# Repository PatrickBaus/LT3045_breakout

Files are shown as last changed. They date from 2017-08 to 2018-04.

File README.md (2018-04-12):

LT3042/LT3045 Breakout Board
===================

This repository contains the KiCAD PCB project files for a breakout board for the Linear Technologies LT3042/LT3045  ultralow noise, ultrahigh PSRR, 200/500 mA LDO regulator (http://www.linear.com/product/LT3042, http://www.linear.com/product/LT3045).

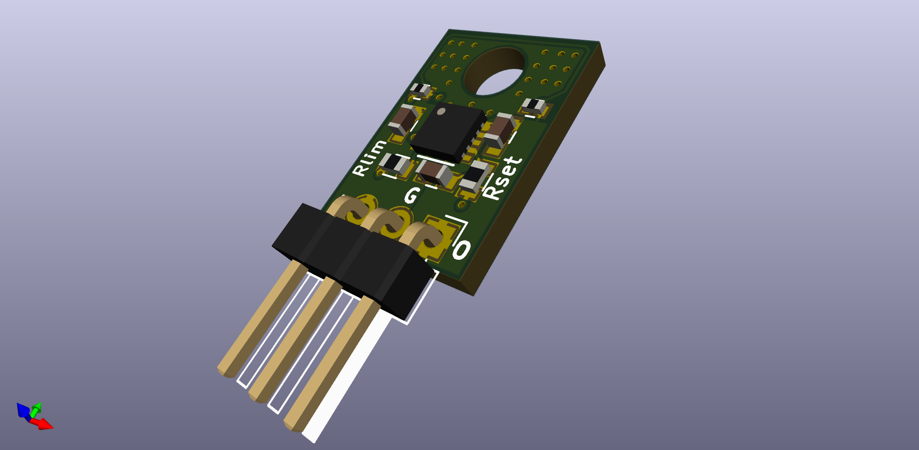
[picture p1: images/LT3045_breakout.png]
LT3045 breakout board


About
-----
This breakout board supports both the LT3042 and LT3045 LDO regulator. The package is designed as a drop-in replacement for the popular 78xx series.

The root folder contains the KiCAD files and the bill of materials, while the gerber files can be found in the [/gerber](gerber/) folder.

Thermal considerations
-----
The breakout board was tested with an LT3045 with different heat sink configurations to give an estimate on the expected temperature rise. This should help with the decision whether to add a heat sink or not. The test was done using a 35 µm (1 oz./ft²) copper board. The LT3045 was configured for an 11 V output from a 13 V input running at ~500 mA.

Using a thermal imaging camera the temperature was measured and the thermal resistance was calculated using the known ambient temperature (~23 °C).

##### No Heat Sink
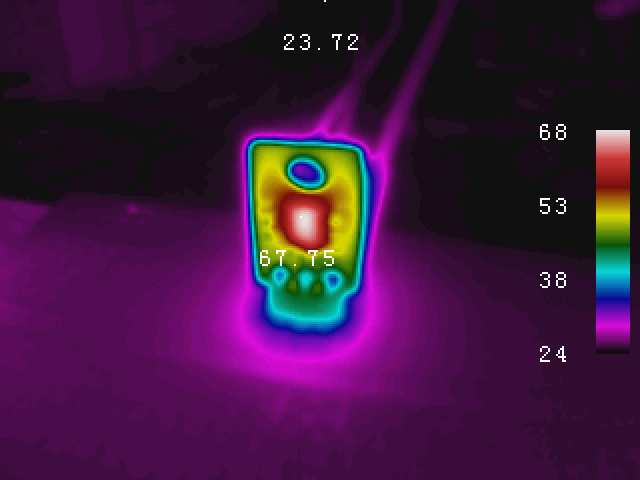
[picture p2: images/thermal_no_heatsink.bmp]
LT3045 no heat sink


##### Using a 25 K/W Heat Sink
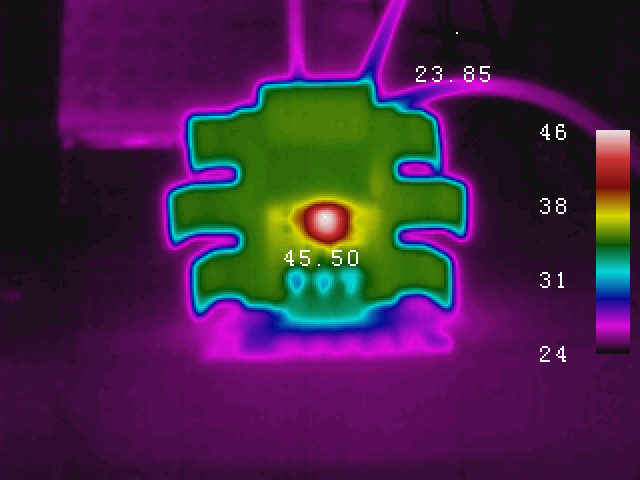
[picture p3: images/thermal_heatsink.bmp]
LT3045 + heat sink

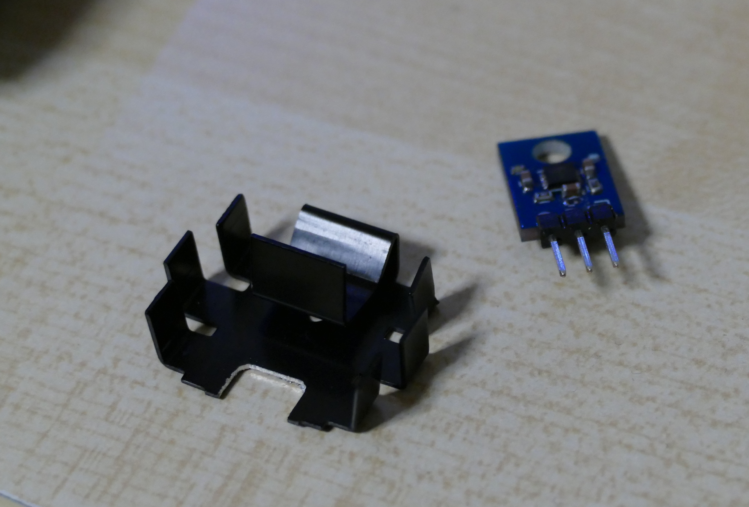
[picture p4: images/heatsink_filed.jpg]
Heat sink filed out


Dropping 2 V @ 500 mA, a Fischer Elekronik [FK 220 SA 220](http://www.fischerelektronik.de/web_fischer/en_GB/heatsinks/C02/Attachable%20heatsink/PR/FK220_SA_220_/datasheet.xhtml) heat sink was used without any thermal compound. Because of the mounting style of the pin header (contacts on the back side of the board) some slight modification of the heat sink is required. A small cutout needs to be made using a file. If the heatsink is to be attached permanetely some thermal adhesive to glue it in place is recommended.

##### Summary Table

|Heat Sink|Power Dissipated|Thermal Resistance|
|---|---|---|
|None |~1 W |~44 K/W |
|25 K/W |~1 W |~22 K/W |

I do recommend using a heat sink or bolting the LT3045 PCB down onto the main PCB when running the LT3045 @ 500 mA. Although the chip is within its design specifications, running it at more than 60 °C will shorten its live and touching it can be rather unpleasant. Any small heat sink should be sufficient at room temperature, but your milage may vary.

Related Repositories
-------------
See the following repositories for more information

KiCAD footprints: https://github.com/PatrickBaus/footprints.pretty

KiCAD 3D models: https://github.com/PatrickBaus/footprints.3dshapes

KiCAD schematic libraries: https://github.com/PatrickBaus/KiCad-libraries

License
-------

This work is released under the Cern OHL v.1.2
See www.ohwr.org/licenses/cern-ohl/v1.2 or the included LICENSE file for more information.

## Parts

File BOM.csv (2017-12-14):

Date: | 2017-12-14T22:19:19 CET
Tool: | Eeschema (2017-06-16 revision 2018d4894)-master
Component Count: | 10
Ref | Qnty | Value | Cmp name | Footprint | Description | Vendor
C3, C1, C2, | 3 | 10u | GRM188R6YA106MA73D | Capacitors_SMD:C_0603 | Unpolarized capacitor | Murata
J1, | 1 | CONN_01X03 | 68016-403HLF | Pin_Headers:Pin_Header_Angled_1x03_Pitch2.54mm | Generic connector, single row, 01x03 | Amphenol
R1, | 1 | 120k | RR0816P-124-D | Resistors_SMD:R_0603 | Resistor | Susumu
R2, | 1 | 300 | RR0816P-301-D | Resistors_SMD:R_0603 | Resistor | Susumu
R3, | 1 | 200k | MCS04020C2003FE000 | Resistors_SMD:R_0402 | Resistor | Vishay
R4, | 1 | 5.6k | RR0510P-562-D | Resistors_SMD:R_0402 | Resistor | Susumu
U1, | 1 | LT3045EDD | LT3045EDD | Housings_DFN_QFN:DFN-10-1EP_3x3mm_Pitch0.5mm | 20V, 500mA, Ultralow Noise, Ultrahigh PSRR Linear Regulator, DFN Package | Linear Technology
W1, | 1 | NET-TIE |  | Custom footprints:NET-TIE-0.15mm

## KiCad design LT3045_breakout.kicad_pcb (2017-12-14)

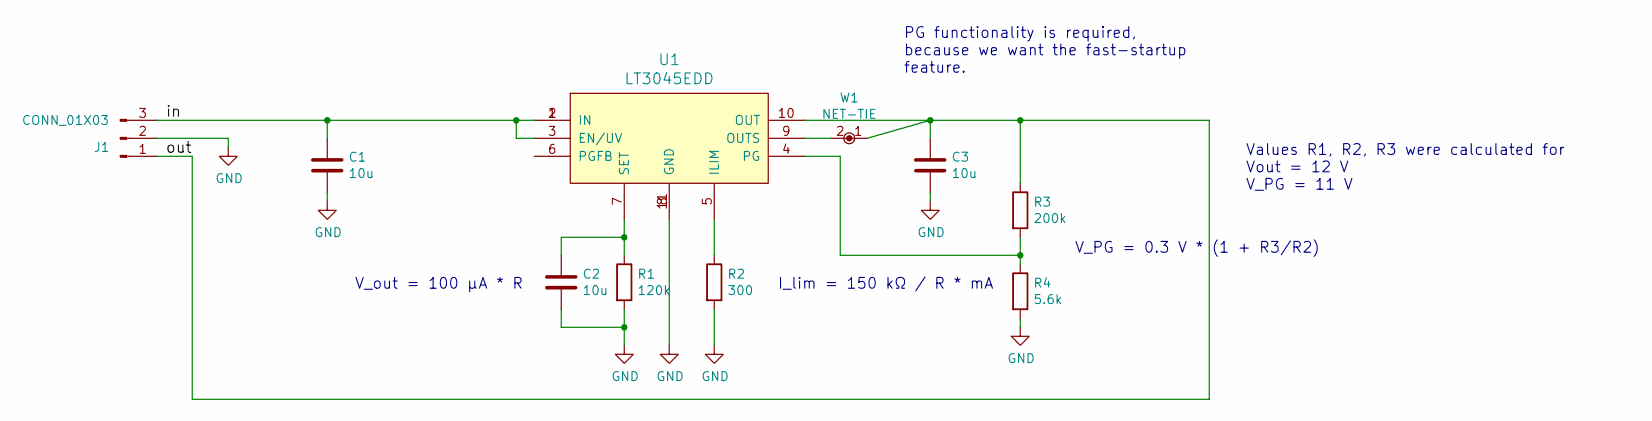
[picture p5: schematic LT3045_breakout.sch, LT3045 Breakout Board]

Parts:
C1, C2, C3: 10u; C_0603
J1: CONN_01X03; Pin_Header_Angled_1x03_Pitch2.54mm
R1: 120k; R_0603
R2: 300; R_0603
R3: 200k; R_0402
R4: 5.6k; R_0402
U1: LT3045EDD; DFN-10-1EP_3x3mm_Pitch0.5mm
W1: NET-TIE; NET-TIE-0.15mm

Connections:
/in: C1.1, J1.3, U1.1 (IN), U1.2 (IN), U1.3 (EN/UV)
/out: C3.1, J1.1, R3.1, U1.10 (OUT), W1.1
GND: C1.2, C2.2, C3.2, J1.2, R1.2, R2.2, R4.2, U1.8 (GND), U1.11
unnamed: C2.1, R1.1, U1.7 (SET)
unnamed: R2.1, U1.5 (ILIM)
unnamed: R3.2, R4.1, U1.4 (PG)
unnamed: U1.9 (OUTS), W1.2

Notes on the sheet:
PG functionality is required, because we want the fast-startup feature.
V_out = 100 µA * R
I_lim = 150 kΩ / R * mA
V_PG = 0.3 V * (1 + R3/R2)
Values R1, R2, R3 were calculated for Vout = 12 V V_PG = 11 V

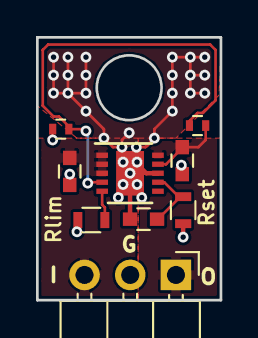
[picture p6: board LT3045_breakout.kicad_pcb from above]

Board: 2 copper layers, 10.2 x 14.6 mm, 10 parts (0 on the bottom side), 7 nets.

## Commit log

2017-08-11 Added label '78xx' to the board Added .gitignore file
    [LT3045_breakout.kicad_pcb]
2017-08-12 Moved via to have a better guard ring for the setpoint
    [LT3045_breakout.kicad_pcb]
2017-08-12 Updated Gerber files
    [LT3045_breakout-B.Cu.gbr, LT3045_breakout-B.Mask.gbr, LT3045_breakout-B.SilkS.gbr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]
2017-08-12 Added more descriptive text to the board
    [LT3045_breakout.kicad_pcb]
2017-08-15 Removed PGFB pull resistor. We do not need that.
    [LT3045_breakout-B.Cu.gbr, LT3045_breakout-B.Mask.gbr, LT3045_breakout-B.SilkS.gbr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]
2017-08-15 Changed resistor values to outout 12V@500mA
    [LT3045_breakout.kicad_pcb, LT3045_breakout.sch]
2017-08-16 Added text to denote Rlim and Rset Changed 3d model of the pin header
    [LT3045_breakout.kicad_pcb]
2017-08-16 Updated picture of the board
2017-08-16 Moved GND label on front silk screen Updated gerber files
    [LT3045_breakout.kicad_pcb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]
2017-12-14 Updated to v1.1 Added BOM Removed old gerber files Updated component values on the pcb board
    [BOM.csv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]
2017-12-14 Fixed layer description
    [LT3045_breakout.kicad_pcb]
2017-12-14 Changed units from inch to metric
    [LT3045_breakout-NPTH.drl, LT3045_breakout-PTH.drl]
2017-12-14 Updated libraries
    [LT3045_breakout.kicad_pcb, LT3045_breakout.sch]
2018-04-12 Added more info on using a heat sink

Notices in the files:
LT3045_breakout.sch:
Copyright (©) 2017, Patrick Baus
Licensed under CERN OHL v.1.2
